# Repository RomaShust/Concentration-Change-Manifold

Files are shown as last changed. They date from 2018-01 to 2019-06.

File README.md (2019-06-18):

# Concentration-Change-Manifold

Manifold for rapid switches of odor concentration using air dilution of the main stream. For each change of concentration, pair of valve solenoids are activated. One of the solenoids deliver air, the second one activate vacuum. On each pair of solenoids we have manual check valves that allows impedance adjustment in air and vacuum lines. To keep total flow constant, we match impedances between each pair of solenoids. Different pairs of needle valves are tuned for different impedances, this way activation of different pair controls different concentration. Vacuum line is under 60 psi pressure (can be reduced). Lee valves can be driven at 5, 12 or 24V.

| Part name | Manufacturer | Catalog # | # of items | Price per item ($) |
| --- |:---:|---:|---:|---:|
| Solenoid | The Lee Company | LHQA2411220H | 8 | 87 |
| Check valve | Beswick Engineering | NV3H-1012-3-S | 8 | 35.2 |
| Fittings | STAR | 10-32 x 1/16 barb | 8 | 1.5 |

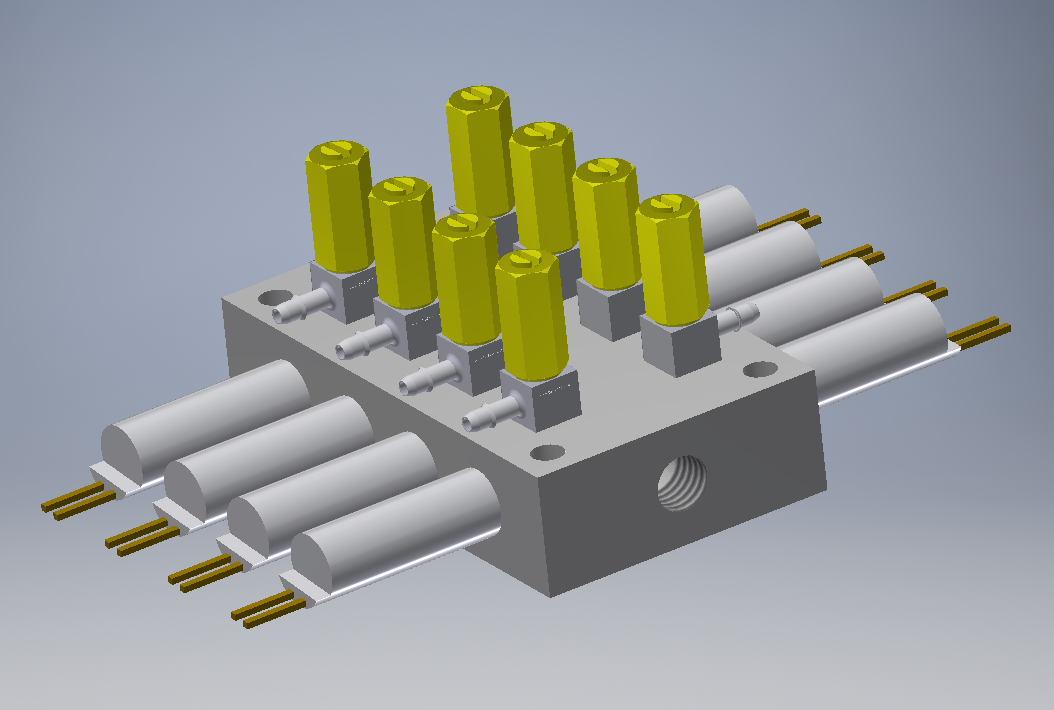
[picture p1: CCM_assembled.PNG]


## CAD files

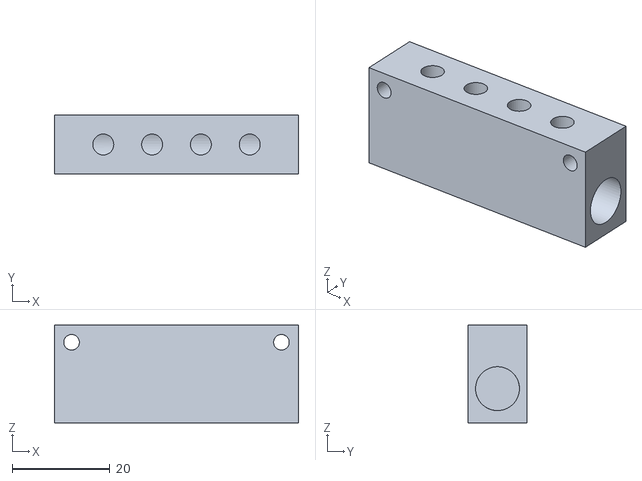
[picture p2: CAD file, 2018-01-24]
AirVacManifold_v2.stl
50.0 x 12.0 x 20.0

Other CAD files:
Manifold_v5.dwg
AirVacManifold_v2.dwg
AirVacManifold_v2.ipt
Manifold_v5.ipt

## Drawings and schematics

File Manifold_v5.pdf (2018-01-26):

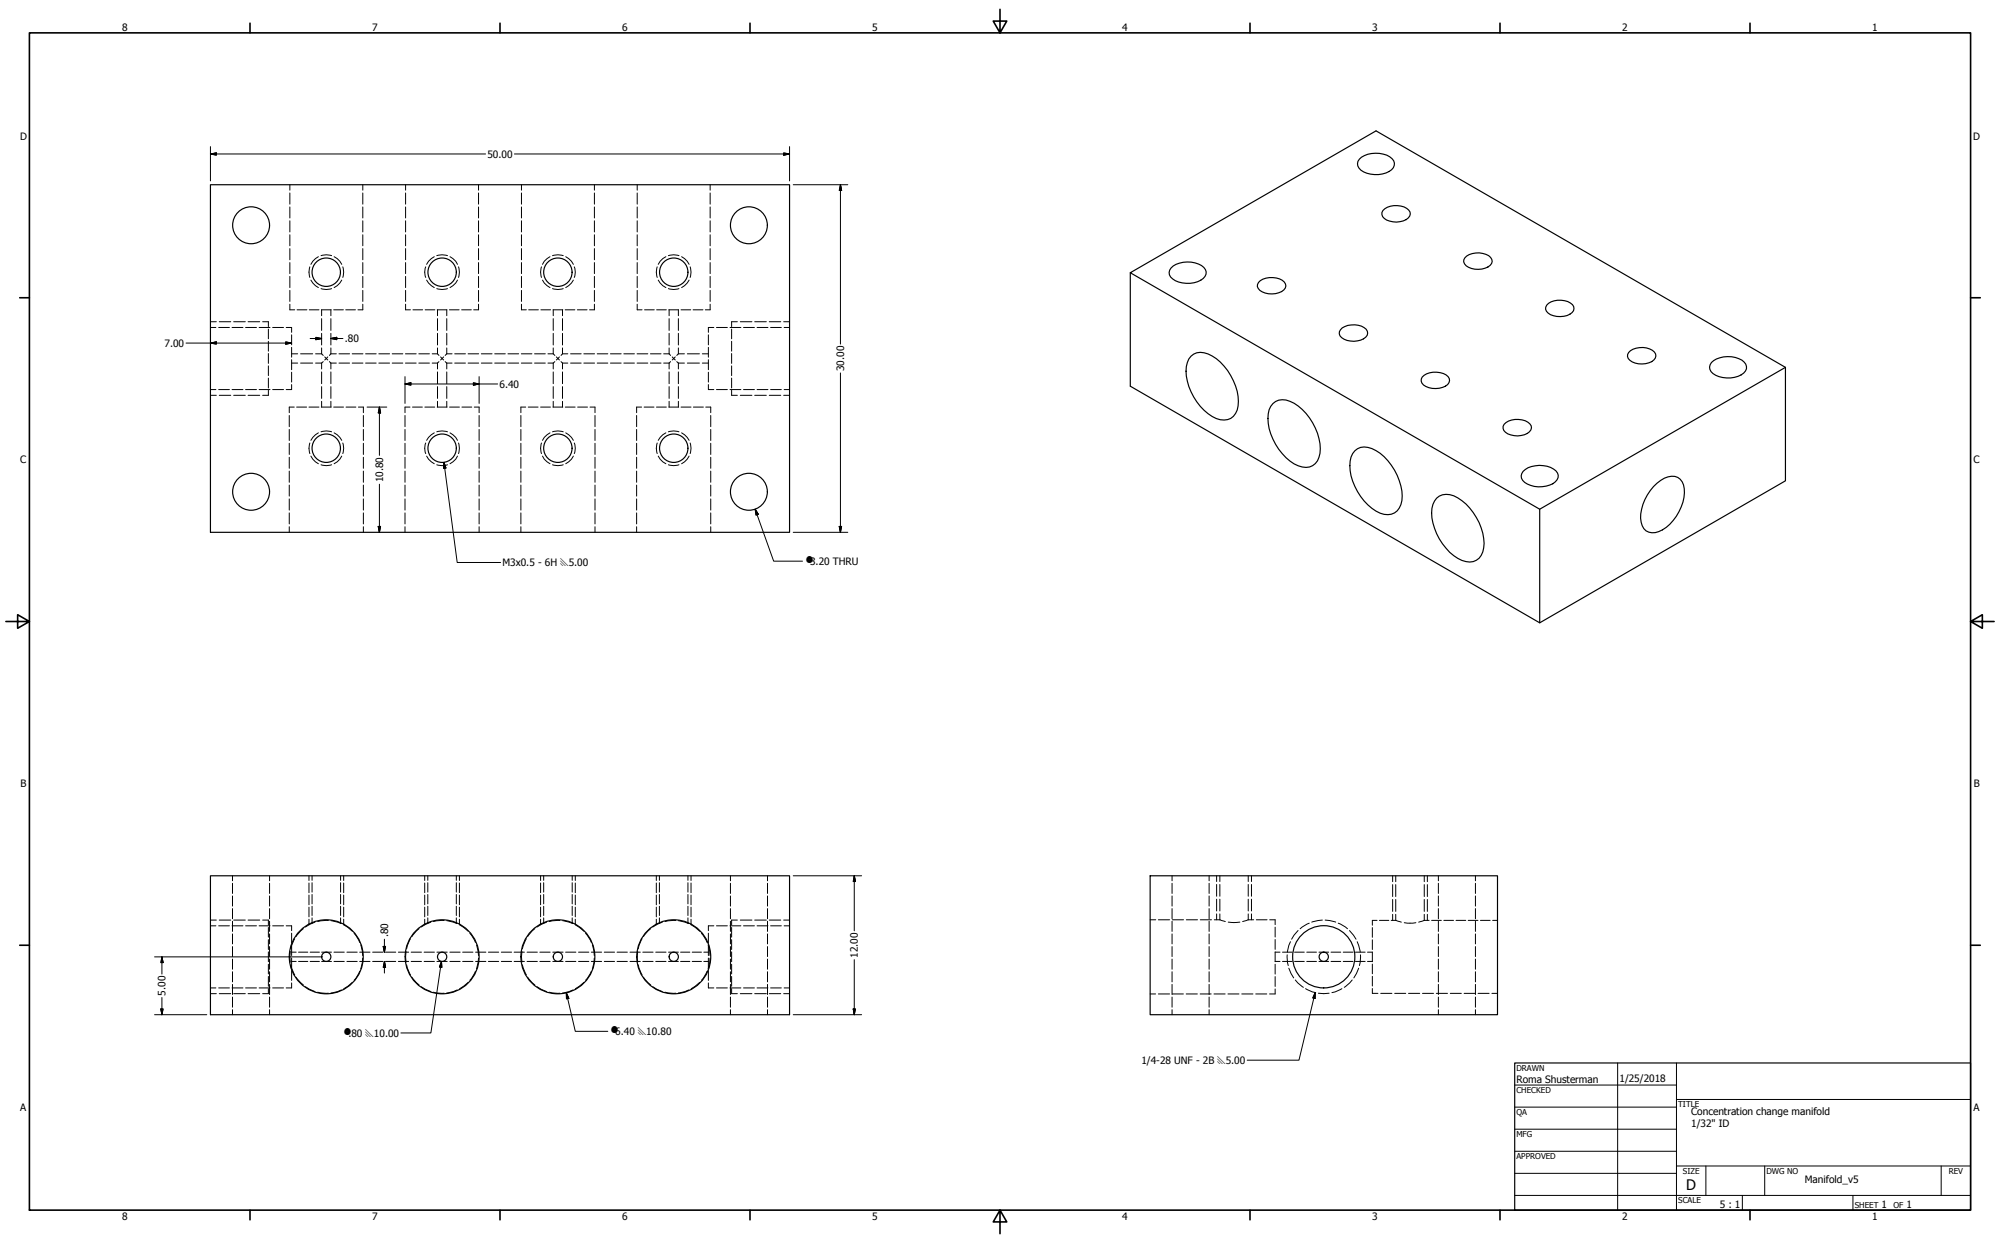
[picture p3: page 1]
SHEET 1 OF 1; DRAWN; CHECKED; MFG; APPROVED; Roma Shusterman; DWG NO; SIZE D; SCALE; REV; 3.20 THRU; 1/4-28 UNF - 2B # 5.00; Manifold_v5

TITLE
Concentration change manifold

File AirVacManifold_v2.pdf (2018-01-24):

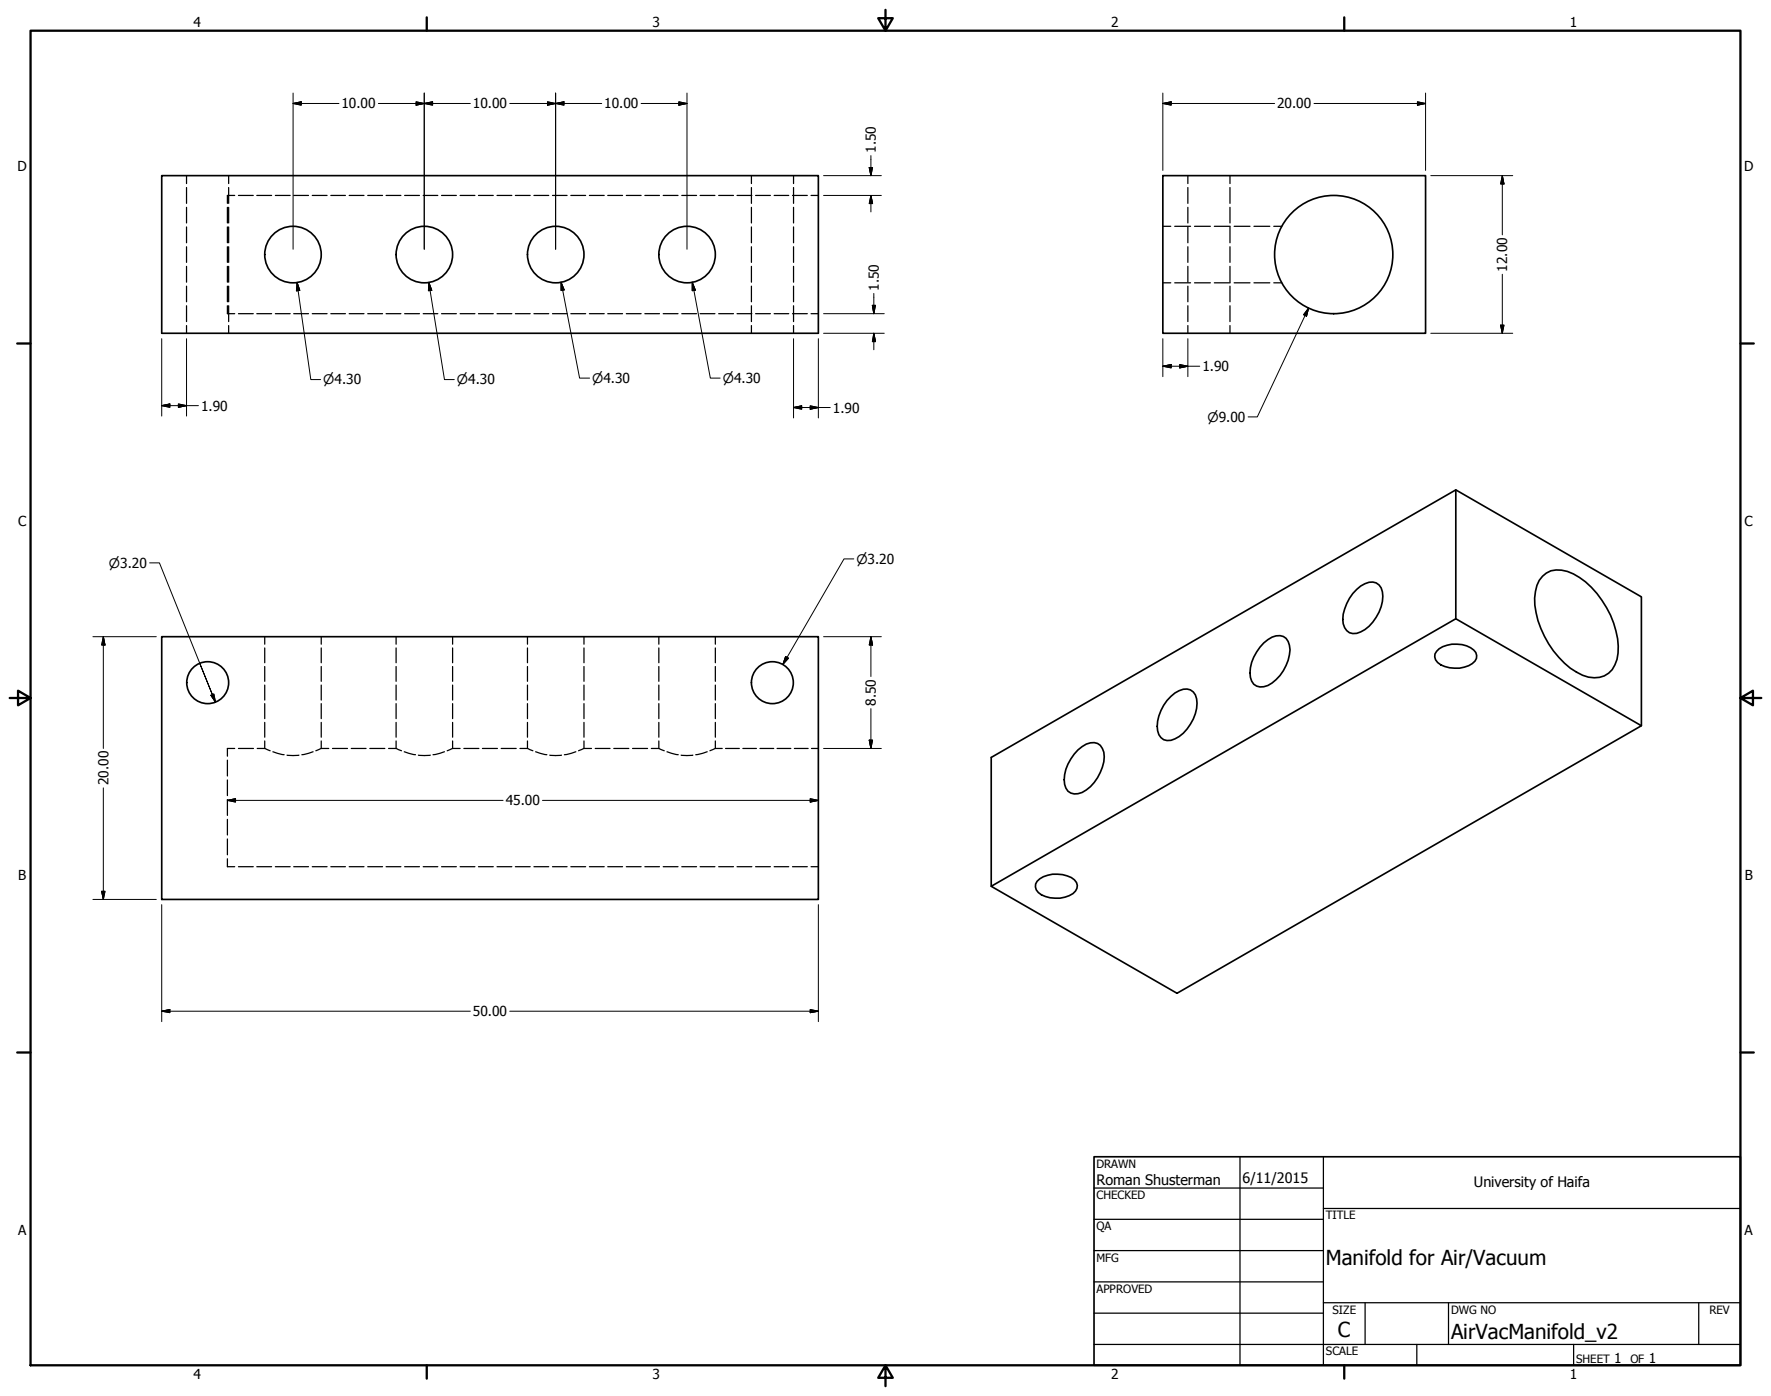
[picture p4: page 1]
SHEET 1 OF 1; DRAWN; CHECKED; MFG; APPROVED; Roman Shusterman; DWG NO AirVacManifold_v2; TITLE; SIZE C; SCALE; REV

University of Haifa

Manifold for Air/Vacuum

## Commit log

2018-01-24 Add files via upload
    Current version allows 4 independent lines, each line at different impedance
    [AirVacManifold_v2.dwg, AirVacManifold_v2.ipt, AirVacManifold_v2.stl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]
2018-01-26 Modifications in check valve and solenoid position
    Version 5 includes:
    1. Minor changes in check valves positioins
    2. Solenoids location where shifted by 1mm not to interfere with check valves
    [Manifold_v4.dwg, Manifold_v4.ipt, Manifold_v5.dwg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]
2019-06-18 Update README.md
    price update of Beswick needle valve
